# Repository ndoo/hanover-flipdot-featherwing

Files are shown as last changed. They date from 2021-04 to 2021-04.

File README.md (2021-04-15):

# hanover-flipdot-featherwing
Hanover Flip-dot Controller for Adafruit HUZZAH32 Feather

## GPIO Assignment

| GPIO | Function | Pulldown |
|---|---|---|
| 13 | Coil Pulse | 10K |
| 12 | Enable Dot Board 1 | 10K |
| 27 | Enable Dot Board 2 | 10K |
| 33 | Enable Dot Board 3 | 10K |
| 15 | Enable Dot Board 4 | 10K |
| 32 | Column Advance & Row Reset | 10K |
| 14 | Column Reset | 10K |
| 21 | Row Advance | 10K |
| 25 | Dot Set/Unset | 10K |

## Acknowledgements

I would be remiss to not credit [Damien Walsh's prior analysis and work on Hanover Flip-dot boards](https://damow.net/fun-with-flip-dot-displays/).

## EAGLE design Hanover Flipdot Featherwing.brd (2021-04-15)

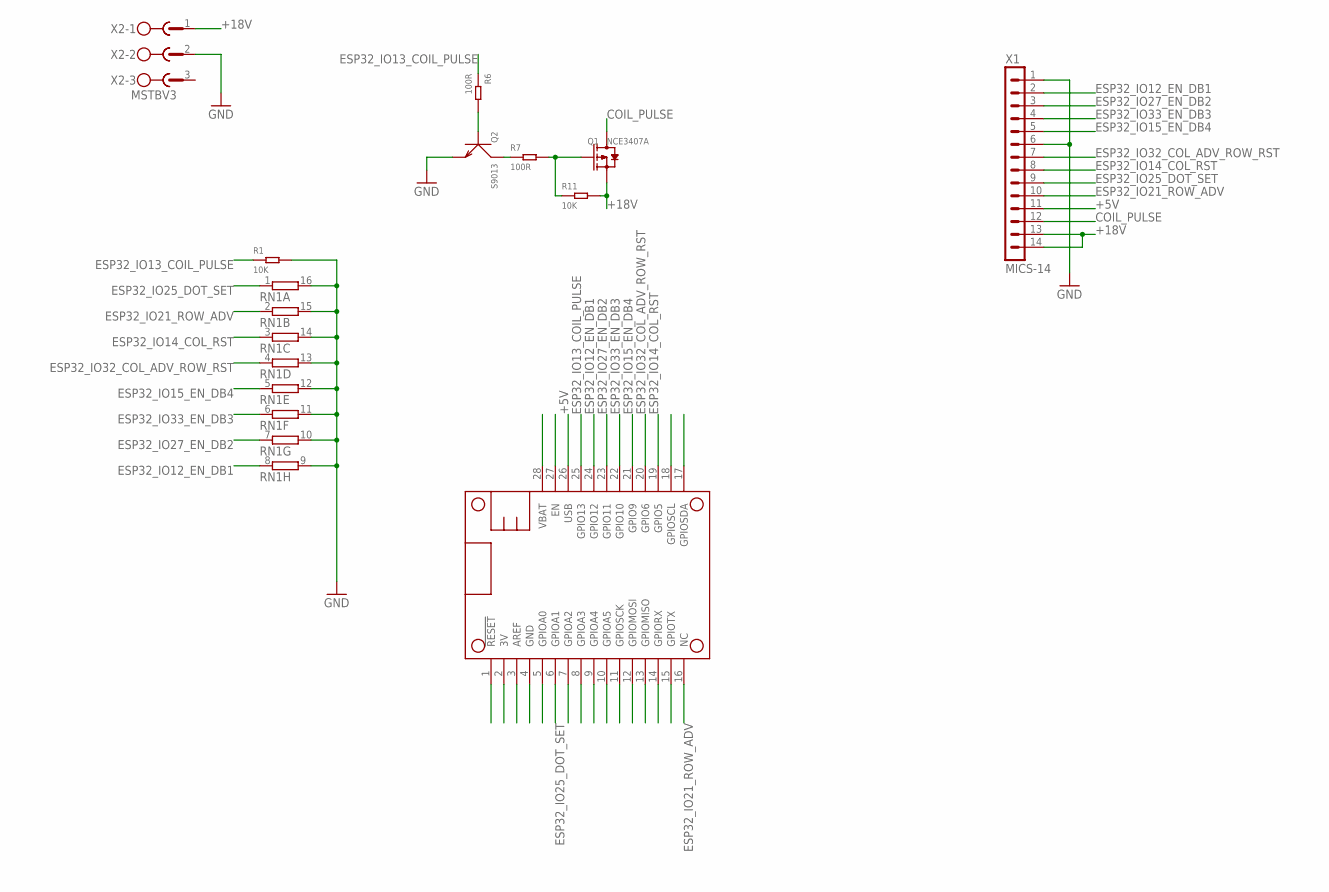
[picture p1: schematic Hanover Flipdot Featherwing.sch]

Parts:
MS1: FEATHERWING
Q1: NCE3407A; SOT-23
Q2: S9013; SOT-23
R1, R11: 10K; R0603
R6, R7: 100R; R0603
RN1: 8R-NEXB2HV; EXB2HV
X1: MICS-14
X2: MSTBV3

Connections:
3V: MS1.2 (3V)
+5V: MS1.26 (USB), X1.11
+18V: Q1.2 (S), R11.2, X1.13, X1.14, X2.1
AREF: MS1.3 (AREF)
COIL_PULSE: Q1.3 (D), X1.12
ESP32_IO12_EN_DB1: MS1.24 (GPIO12), RN1.8 (1), X1.2
ESP32_IO13_COIL_PULSE: MS1.25 (GPIO13), R1.1, R6.1
ESP32_IO14_COL_RST: MS1.19 (GPIO5), RN1.3 (1), X1.8
ESP32_IO15_EN_DB4: MS1.21 (GPIO9), RN1.5 (1), X1.5
ESP32_IO21_ROW_ADV: MS1.16 (NC), RN1.2 (1), X1.10
ESP32_IO25_DOT_SET: MS1.6 (GPIOA1), RN1.1, X1.9
ESP32_IO27_EN_DB2: MS1.23 (GPIO11), RN1.7 (1), X1.3
ESP32_IO32_COL_ADV_ROW_RST: MS1.20 (GPIO6), RN1.4 (1), X1.7
ESP32_IO33_EN_DB3: MS1.22 (GPIO10), RN1.6 (1), X1.4
GND: MS1.4 (GND), Q2.2 (E), R1.2, RN1.9 (2), RN1.10 (2), RN1.11 (2), RN1.12 (2), RN1.13 (2), RN1.14 (2), RN1.15 (2), RN1.16 (2), X1.1, X1.6, X2.2
unnamed: Q2.1 (B), R6.2
unnamed: Q1.1 (G), R7.2, R11.1
unnamed: Q2.3 (C), R7.1
VBAT: MS1.28 (VBAT)

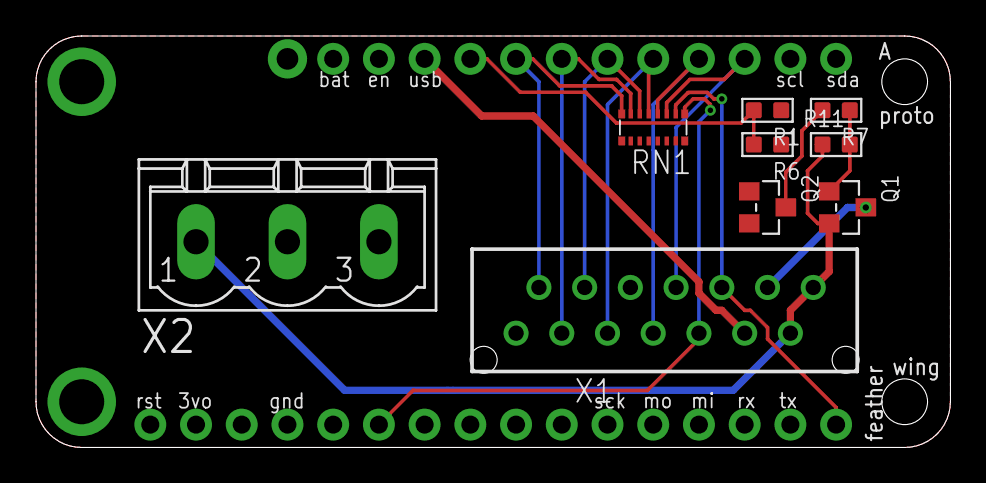
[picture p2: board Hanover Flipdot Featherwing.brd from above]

Board: 2 copper layers, 50.8 x 22.9 mm, 10 parts (0 on the bottom side), 16 nets.
